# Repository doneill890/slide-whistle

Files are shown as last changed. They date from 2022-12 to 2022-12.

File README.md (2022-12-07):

# Autonomous Slide Whistle Portfolio
This repo contains a summary of the design of a slide whistle and LCD screen that could be controlled in parallel with an MCU and an FPGA. The design and results of the Project are documented here, along with the necessary source files.

The website presenting this information nicely can be accessed at [https://doneill890.github.io/slide-whistle/](https://doneill890.github.io/slide-whistle/)

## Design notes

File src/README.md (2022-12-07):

# Project file sources

This project used source files in three capacities. The MCU used embedded C files for the STM32L4 processor to drive the motor, send data to the FPGA, and drive the transistors turning the fan on and off. The FPGA used Systemverilog to describe the hardware needed to recieve information from the MCU via SPI, synchronize it, and send it with the correct configuration to the LCD screen. Finally, the 3D printed parts were all created in SolidWorks, and their files are included here. Note that these solidworks files were based in part on the CAD representations for similar gears provided by McMaster-Carr [[3](https://www.mcmaster.com/gears/metal-gears-and-gear-racks-20-pressure-angle/)]

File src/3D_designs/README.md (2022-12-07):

# 3D Design CAD files

All of the 3D printed parts of this project were designed using SolidWorks CAD software. The files for these parts can be found here, along with an assembly that indicates how to put them together. They were adapted from the 3D representations of several gears distributed by McMaster-Carr [[3](https://www.mcmaster.com/gears/metal-gears-and-gear-racks-20-pressure-angle/)]. Each part was printed at Harvey Mudd's Makerspace using FLSUN Super Racer printers using PLA provided by the school at no cost.

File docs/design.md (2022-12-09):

---
layout: page
title: Design
permalink: /design/
---

# New Hardware

There are several pieces of new hardware in this project, including the stepper motor that moves the slide whistle pull rod to different locations, the fan that blows air into the mouth piece, and the LCD that displays the song title and notes. The specific design process for implementing these features are detailed in the sections below.

# Microcontroller Design

The MCU performs three main functions: it controls the stepper motor to move the slide whistle pull rod to play different notes, it sends the song title and note information to the FPGA over SPI, and it controls the fan to blow air into the slide whistle mouthpiece. 

To control the stepper motor, the MCU sends pulses that correspond to steps (1.8° rotations of the motor) and a direction signal (to indicate clockwise or counterclockwise rotation) to an A4988 stepper motor driver. The A4988 then sends the appropriate signals to the coils in the stepper motor. The wiring for this setup can be seen on the Documentation page. In order to send an exact number of pulses to the stepper motor to move the slide whistle pull rod to a specific location, the Timer 16 peripheral was used in one-shot PWM mode along with the repetition counter register (RCR) set to the desired number of pulses. In one-shot mode, the timer is disabled after one period of the PWM has finished. If the repetition counter register is not 0, however, the timer update event is masked, so the timer continues running [[1](https://www.st.com/resource/en/application_note/dm00236305-generalpurpose-timer-cookbook-for-stm32-microcontrollers-stmicroelectronics.pdf)]. Instead, the RCR decrements after each pulse, and the timer is only disabled once the RCR reaches 0 and the desired number of pulses have been sent.

To send the name of the song to the FPGA, the SPI peripheral was used, along with a GPIO pin to indicate to the FPGA if the information sent is the name of the song or a song note (which determines where the FPGA displays the information on the LCD). 

Since the fan requires 12V and more current than the MCU can safely provide, the MCU could not drive the fan directly. Instead, the MCU controls an NPN transistor (which acts as a switch) to turn the fan on and off. The wiring for this can be seen in the Documentation section.

# FPGA Design

As mentioned above, the FPGA was set up to display characters on the LCD. It was wired using the schematic shown in the Documentaion page. The LCD in this case uses a Hitachi HD44780U LCD controller chip. The FPGA was implemented in a way that could mimic what was described in this controller’s datasheet [[2](https://circuitdigest.com/sites/default/files/HD44780U.pdf)]. This involved creating several finite state machines. 

<div style="text-align: center">
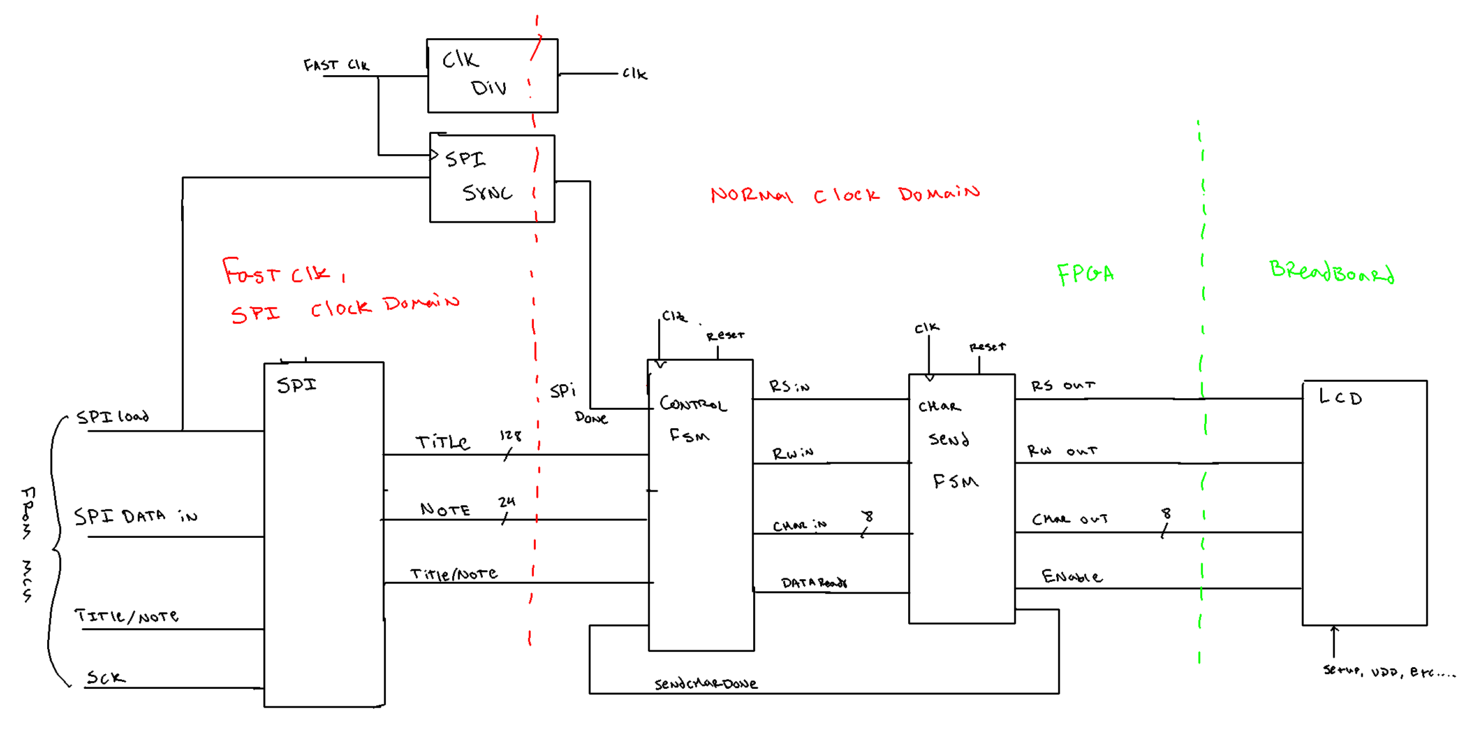
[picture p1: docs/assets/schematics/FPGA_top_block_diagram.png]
  
  <p  style="font-style: italic"> Top level diagram of each part of the FPGA design</p>
</div>

The first FSM, shown below, used to send data to the screen, works as follows: it waits for data to come in from the controller FSM, indicated by a dataReady signal rising to 1. Then it goes through the steps to send the inputs of the correct RS, R/W, Data, and Enable signals to the LCD controller. Once it is done, it raises a 'sendCharDone' signal back to the controller FSM to indicate that the transaction is complete and a new one can be made. This FSM then sits in a wait state again until the controller sends more data.

<div style="text-align: center">
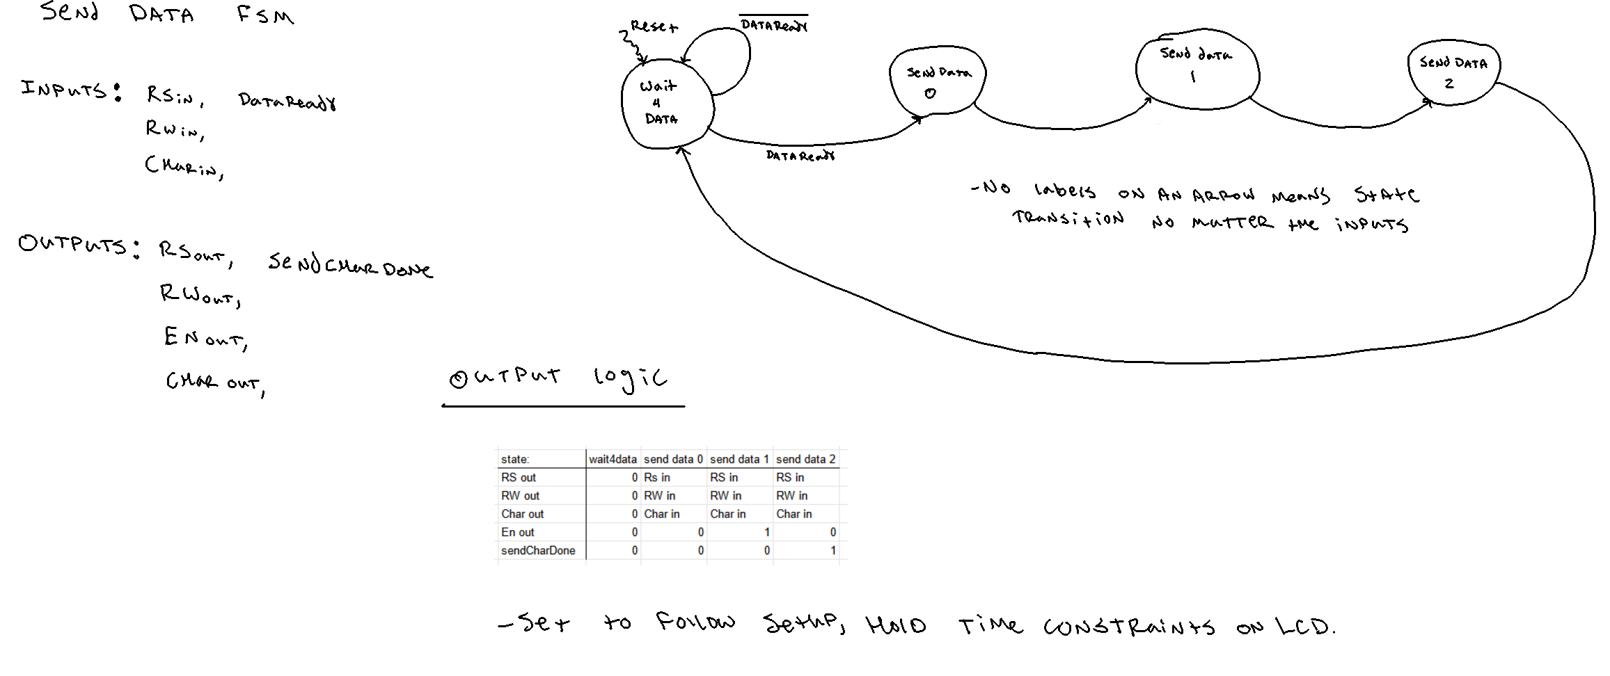
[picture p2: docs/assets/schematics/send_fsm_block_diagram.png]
  
  <p  style="font-style: italic"> FSM for sending data to LCD controller</p>
</div>

The controller FSM is rather more complicated, as it has to decide the setup signals being sent to the LCD and time all the data correctly. Its diagram is shown below. It begins in an initial state, where it waits until a counter has gone past a value corresponding to 40ms. This is due to a 40ms startup time described by the LCD controller [[2](https://circuitdigest.com/sites/default/files/HD44780U.pdf)]. 

Then, this controller FSM sends two setup signals to the LCD to set the correct configuration registers in the LCD. These set up the LCD as having 16 lines of 2 characters and to incriment the cursor each time a character is written. Then the controller FSM goes into a wait state until it receives data from the MCU over SPI. 

When the SPI transaction is done, the controller sends a control signal to the LCD that puts the cursor in the correct position for either the title or the note. Finally, the control FSM sends all the title or note characters to the LCD. Once all the characters are sent, the control FSM goes back to the wait state to await the next chunk of data from the MCU. This entire operation relies on several counter state variables that count the number of characters sent or the time passed. The updating of these values is detailed in the image below. Each time a character is sent to the LCD, the character sender FSM described above is activated by raising the dataReady signal, and the controller FSM remains in the same state until the transaction is complete and sendCharDone is raised. This is true for both control character signals and data characters being displayed on the screen. 

<div style="text-align: center">
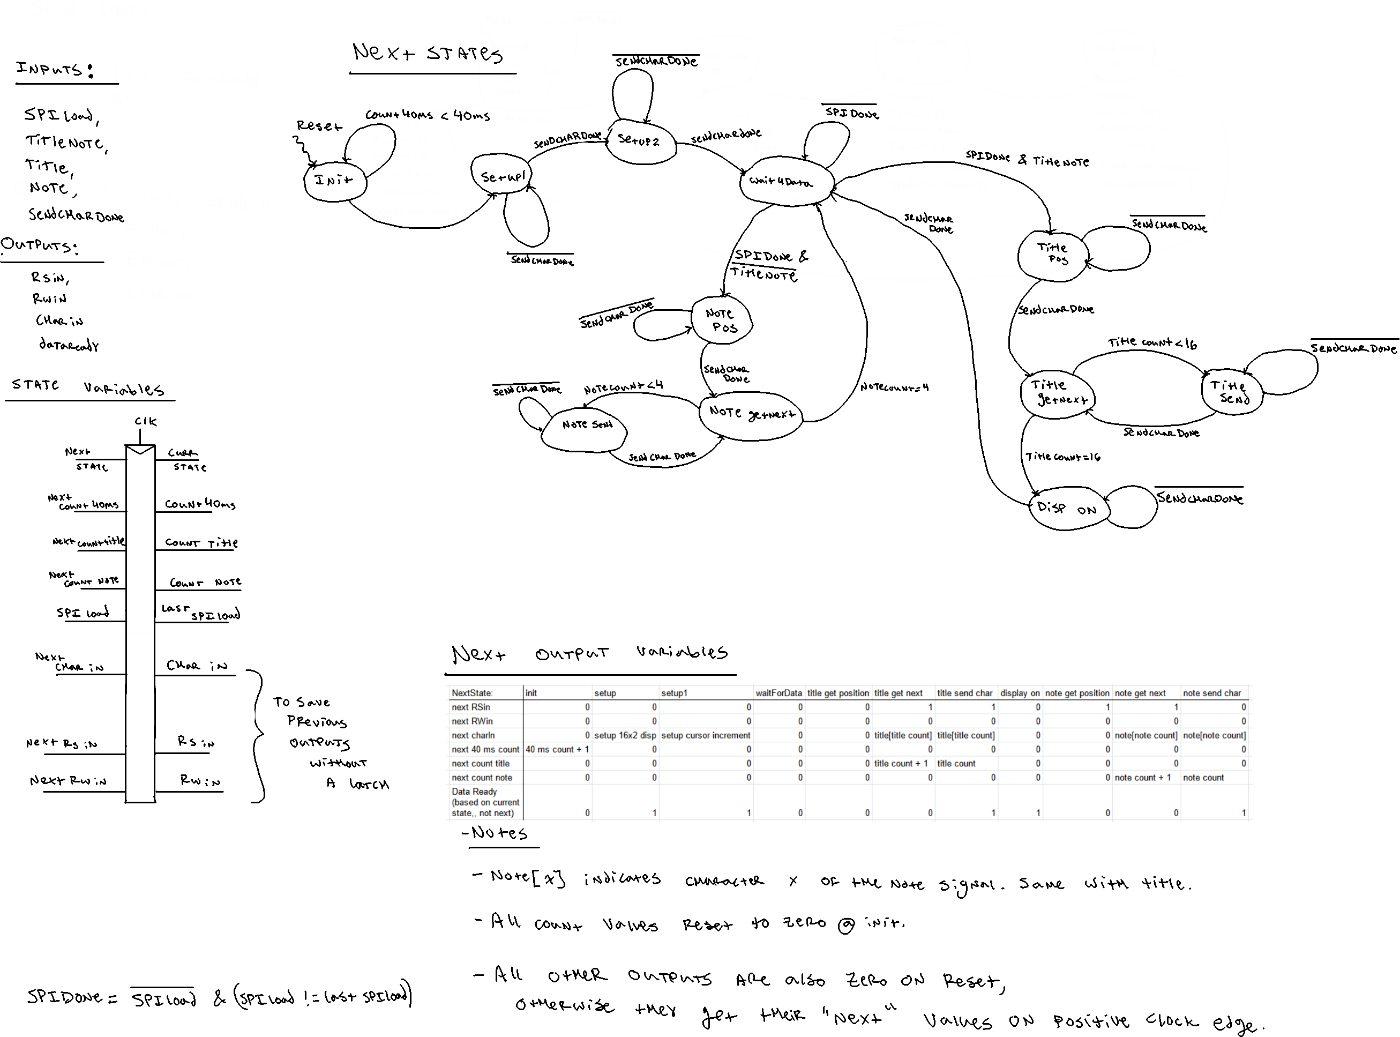
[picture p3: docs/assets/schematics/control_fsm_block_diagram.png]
  
  <p  style="font-style: italic"> FSM for controlling which data and control signals are sent to the LCD</p>
</div>

The FPGA receives the correct data to display on the screen via an SPI transaction from the MCU as the transaction controller. Data only needs to go from controller to peripheral, so the CIPO line is ignored. The SPI reception module in the FPGA listens for transactions using an spiLoad signal from the MCU. Another signal, titleNote, is used to indicate whether the transaction is sending new title data or new note data. The FPGA detects when the spiLoad signal has dropped as an indication that data transfer is done and the title or note are ready to send to the screen. 

One issue with this is that the clock for the controller and data-sending FSMs must be fairly slow. This is due to the fact that most of the commands to the screen take 37 μs [[2](https://circuitdigest.com/sites/default/files/HD44780U.pdf)]. This slow clock was divided down from a 48M MHz fast clock. The issue is that the spiLoad signal may rise and fall within less than a slow clock cycle, which means it would not be detected on the rising edge of the clock. To remedy this, a third synchronizing FSM was created and is shown below. This one used the fast 48 MHz to make sure the spiLoad signal was captured. Then, since the ratio of fast and slow clock frequencies was known, this FSM held an spiDone signal high until it could be detected by the slow clock in the controller FSM. The other data from the SPI transaction was held after the transaction completed, and the transactions come every several hundred ms, so there was no need to synchronize that data as well. In this way, all the information coming out of SPI was synchronized to the slower clock of the other FSMs. 

<div style="text-align: center">
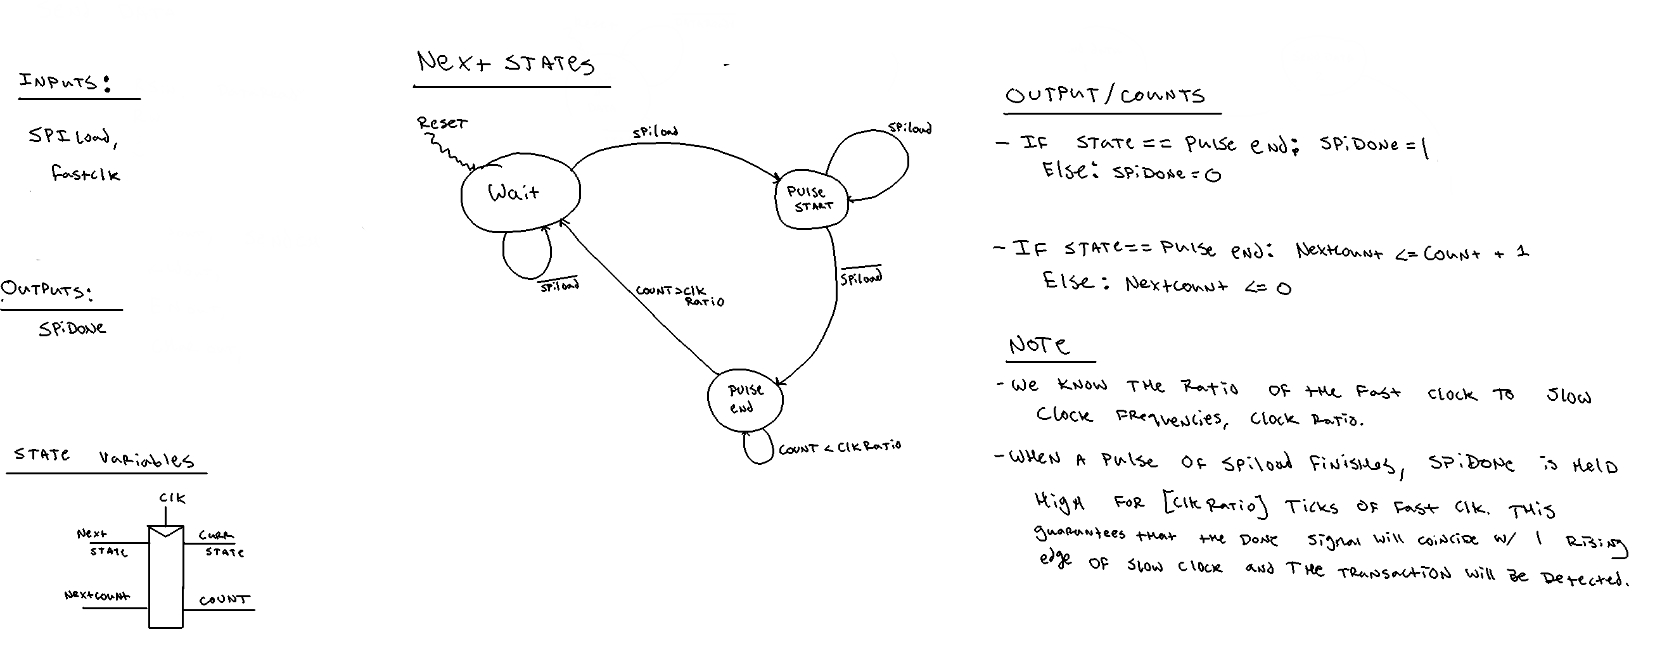
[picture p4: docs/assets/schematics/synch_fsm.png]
  
  <p  style="font-style: italic"> FSM for synchronizing data coming in from SPI to the slower clock domain</p>
</div>

# Hardware Design

The slide whistle has a 3D printed attachment from the fan to the mouthpiece of the whistle. This allows all the air coming out of the fan to be sent into the whistle, and works fairly well to play notes along the entire range of the whistle slide. This piece can be seen below.

<div style="text-align: center">
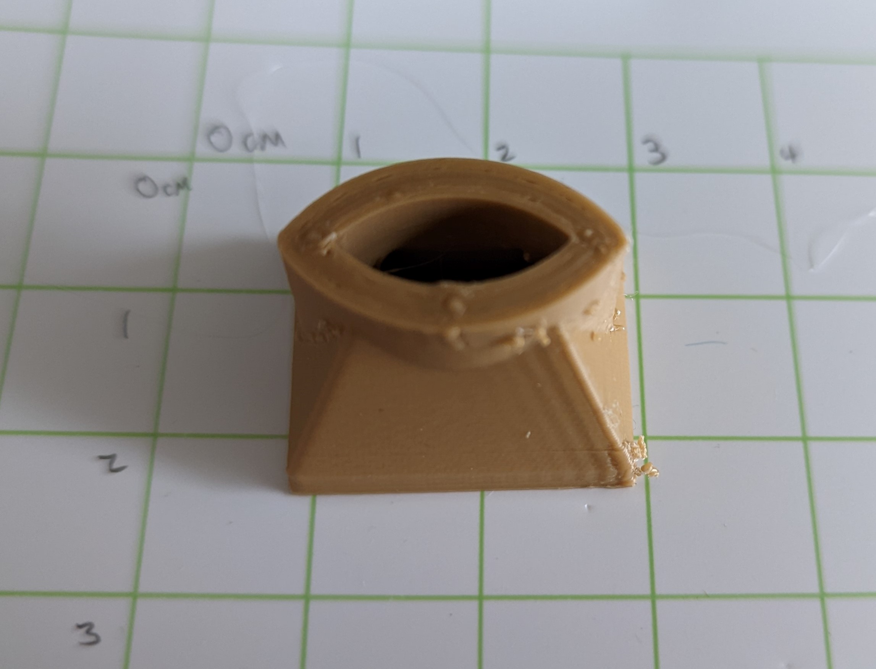
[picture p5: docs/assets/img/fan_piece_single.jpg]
  
  <p style="font-style: italic"> Adapter for slide whistle mouthpiece to attach to a 5015 fan output</p>
</div>

Another set of 3D printed pieces were used to turn the rotational motion of the stepper motor into precise translational motion of the slider. To do this, a rack, pinion, and housing for the motor were all printed out. The housing held the motor without allowing it to move and also provided axles for any additional gears that might have be needed. The pinion gear attaches to the shaft of the motor, and the rack slides back and forth in a loose track attached to the housing. These pieces are shown in the images below.

<div style="text-align: center">
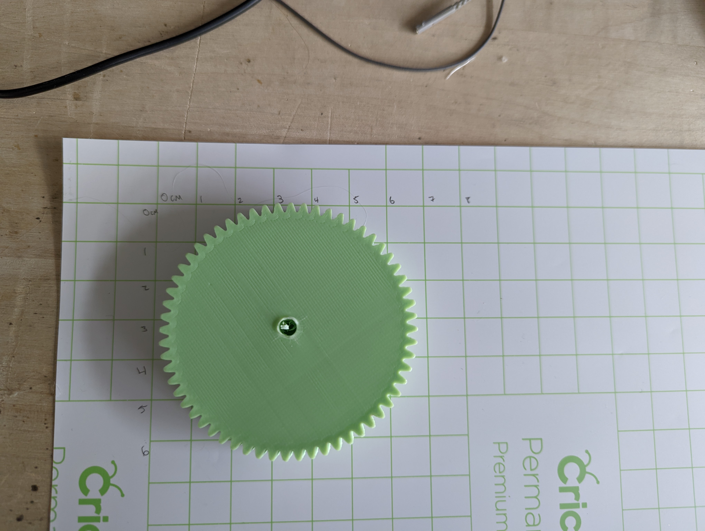
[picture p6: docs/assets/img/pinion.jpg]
  
  <p  style="font-style: italic"> 3 inch pinion gear to be attached to motor shaft</p>
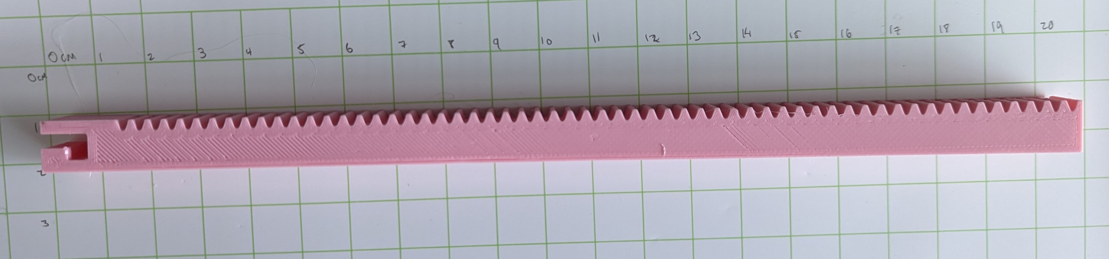
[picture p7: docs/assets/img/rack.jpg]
  
  <p  style="font-style: italic"> Rack gear to turn motor's rotational motion into translational motion along the slide of the whistle</p>
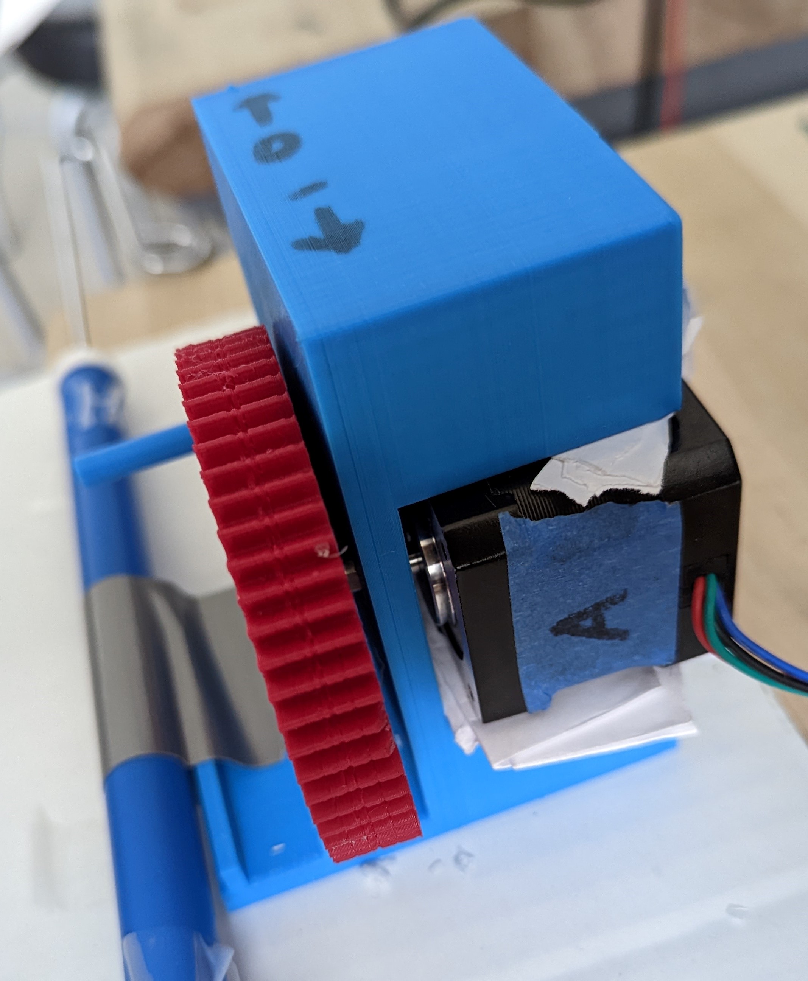
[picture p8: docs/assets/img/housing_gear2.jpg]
  
  <p  style="font-style: italic"> Motor housing with space for the motor and a track for the rack to slide when driven by the pinion gear</p>
</div>

In order to acheive a reasonably high translational speed, 3 inch pinion gears were printed. Initially, it was thought that additional speed would be needed, so more gears and axles were printed to allow the speed to be multiplied. However, increasing the speed of the gears by ratioing with a factor of x means a similar increase in torque needed and decrease in precision by a factor of x. This meant that even one ratio gear speeding up by a factor of 5 needed too much torque and did not have enough precision to hit every note along the slide correctly. Since the team was focusing on slower songs, this idea was abandoned after finding out that the translational speed acheived with a single 3 inch pinion gears was enough. The final assembled design is shown below.

<div style="text-align: center">
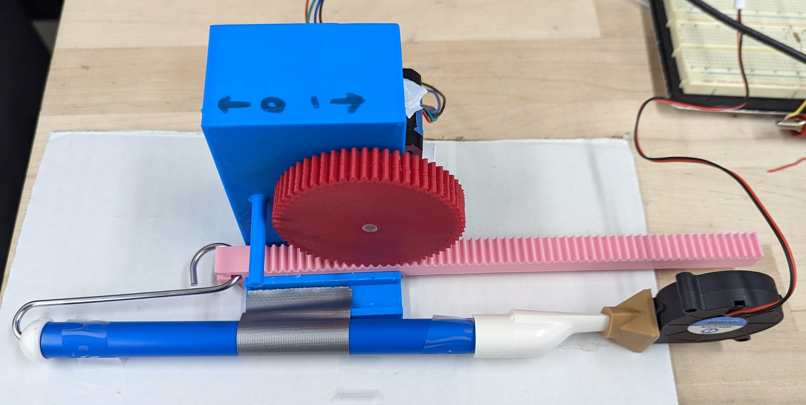
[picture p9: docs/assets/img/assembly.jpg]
    
    <p style="font-style: italic"> The entire assembly of fan, whistle adapter, motor, housing, slide whistle, rack, and pinion</p>
</div>

To encode the notes into the MCU, the team used a tuner app and a measuring tape to find the distances the slide would have to move to acheive a certain note. A function was created in the MCU that took in a note string and gave the corresponding location of the slide in units of cm away from its zero position. Since the step size, gear size, and current position were known, the MCU could then convert the new desired note location to a number of steps and a direction to travel in. It would then send this number of steps and direction to the motor controller, which would turn the gear until the whistle was set up to play the corresponding desired note. 

The steps were 1.8° each, corresponding to a 0.047 in translational motion with a 3 inch pinion gear. This allowed the high precision necessary to play notes in tune. At the highest speed, the motor could move 8 rotations per second. This means that the motor could move the rack the entire 7 inch length of the slide in about 106 ms. Both these values were determined to be satisfactory to play some simple tunes.

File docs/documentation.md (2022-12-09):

---
layout: page
title: Documentation
permalink: /doc/
---

# Schematics
<!-- Include images of the schematics for your system. They should follow best practices for schematic drawings with all parts and pins clearly labeled. You may draw your schematics either with a software tool or neatly by hand. -->

## Overall Block Diagram

<div style="text-align: left">
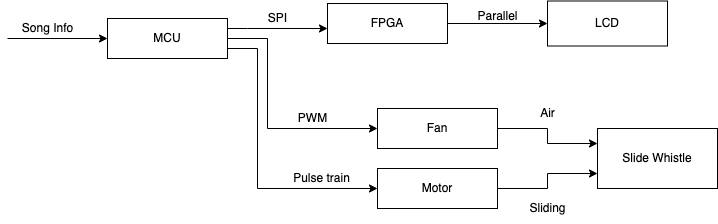
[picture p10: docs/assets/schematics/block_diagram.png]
  
</div>

## Overall system schematic

<div style="text-align: left">
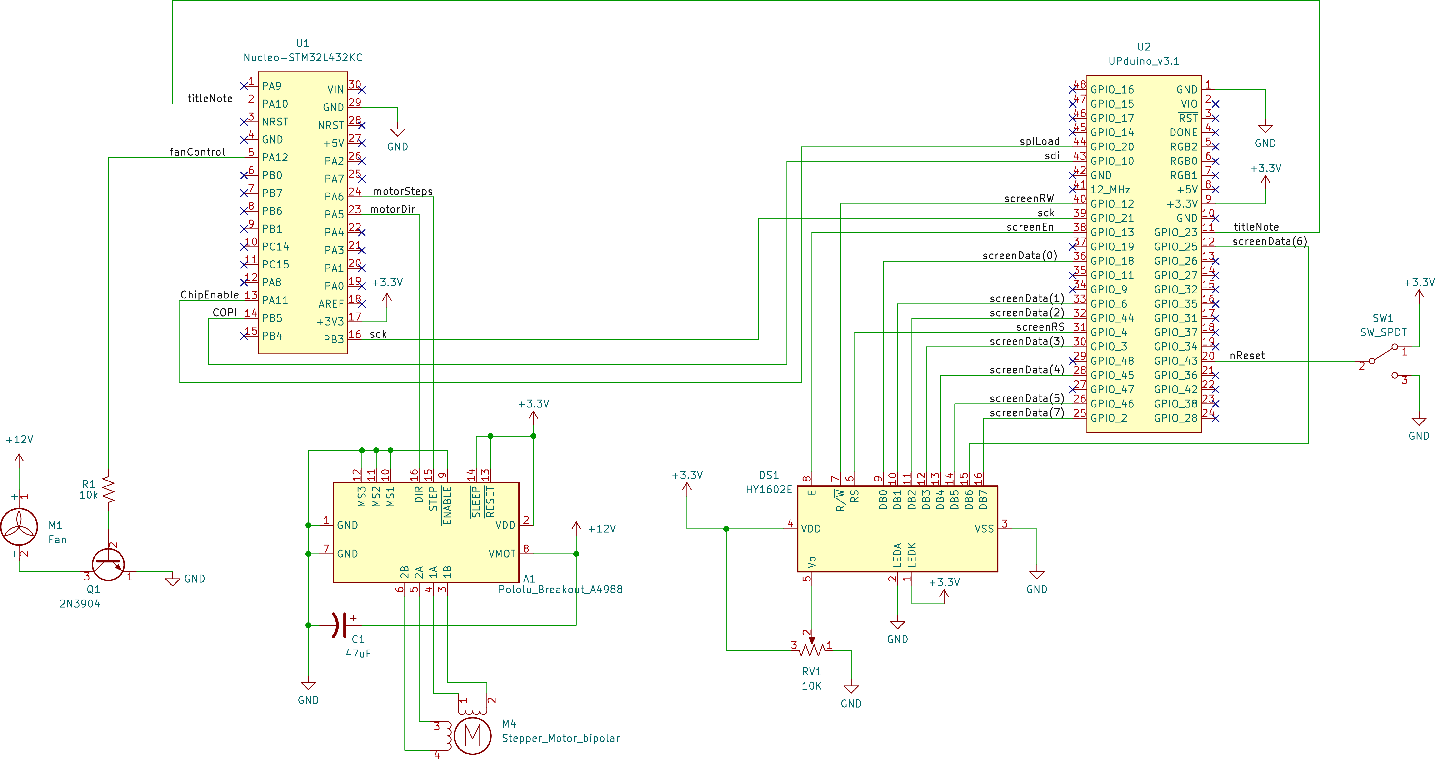
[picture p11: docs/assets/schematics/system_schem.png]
  
  <p style="font-style: italic"> Overall Schematic of entire system, including MCU, FPGA, fan, motor, and LCD. Note that both MCU and FPGA are powered via a USB connection, and the 12V sources come from benchtop power supplies. </p>
</div>

# Source Code Overview

The source code for the project is located in the Github repository [here](https://github.com/doneill890/slide-whistle/tree/main/src). 

The MCU files there can be uploaded to the STM32L432KC microcontroller on the Nucleo development board. They are used to generate the correct signals for the fan power control, motor controller IC, and SPI transactions to the FPGA. All the MCU files beginning with "STM..." were provided to the team by Prof Brake, and contain the necessary functions and definitions to use the CIMSIS library and make the design process easier. 

The FPGA files were uploaded to the ICE40UP5K FPGA on the UPduino v3.1 development board. These describe hardware that takes in SPI messages from the MCU and interfaces with the LCD to print the desired text.

The 3D design files contain the SolidWorks part files used in this project. These were manufactured using the 3D printers at Harvey Mudd's Makerspace on FLSUN Super Racer Printers using standard PLA.
# Bill of Materials

| Item | Part Number | Quantity | Unit Price | Vendor | Link |
| ---- | --- | --- | --- | --- | ---- |
| Lukmaa Slide Whistle | B091JVNBP9 | 1 | $9.99 | Amazon | [link](https://www.amazon.com/Lukmaa-Whistle-Instrument-Parent-Child-Stuffers/dp/B091JVNBP9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) |
| Focus LCDs Character Display | C162D-BW-LW65 | 1 | $13.70 | Digikey | [link](https://www.digikey.com/en/products/detail/focus-lcds/C162D-BW-LW65/13683627) |
| GDSTIME 5015 Fan | C162D-BW-LW65 | 1 | $17.99 | Amazon | [link](https://www.amazon.com/gp/product/B089Y3QPYF/ref=ox_sc_act_title_2?smid=A235LT0EDLFSAR&psc=1) |
| Pololou Stepper Controller Breakout | A4988 | 1 |  | Declan O'Neill | |
| Nucleo STM32L432KC Microcontroller | NUCLEO-L432KC | 1 |  | E155 kit | [link](https://www.st.com/en/evaluation-tools/nucleo-l432kc.html) |
| UPDuino v3.1 ICE40 UP5K FPGA |  | 1 |  | E155 kit | [link](https://upduino.readthedocs.io/en/latest/introduction/introduction.html) |
| NEMA17 Bipolar Stepper Motor | 42A02 | 1 | | Engineering stockroom| |
| PLA for 3D printing |  | 500g | | HMC Makerspace |  |
| NPN Transistor | 2N 3904 | 1 | | Engineering stockroom |  |
| 10 kOhm Potentiometer |  | 1 |  | Engineering stockroom |  |
| SPDT Push-Button Switch |  | 1 |  | E155 kit |  | 
| 47 μF Polarized Capacitor |  | 1 |  | Engineering stockroom |  |
| 1 kOhm Resistor |  | 1 |  | Engineering stockroom |  |

**Total cost: $41.68**

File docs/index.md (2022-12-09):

---
layout: page
title: Project Overview
permalink: /
exclude: true
---

# Project Abstract

In this project, the team aims to create an automated slide whistle that can play a piece of music on its own. The input to the system is an array of notes and durations and the title of the song. A microcontroller (MCU) takes this information and calculates the signals to send to a stepper motor and fan. The fan is directed to blow into the mouthpiece of the slide whistle and the motor controls a rack and pinion attached to the slide whistle pull rod, thus playing music. The MCU also sends the name of the song and the current note over a serial peripheral interface (SPI) to a field programmable gate array (FPGA) which displays that information on an LCD. All of these signals are synchronized so that the slide whistle armature moves and the fan blows to play the correct note for the correct duration and the note is displayed on the LCD all at the same time. 

# Project Motivation

A slide whistle can be a fun and pleasing instrument to play tunes with, but the tedious process of holding the slide whistle, blowing into it, and moving the rod to the correct position to play the desired notes can quickly become laborious and tiresome. The *Autonomous* Slide Whistle removes these inconveniences, providing the user with musical enjoyment at the press of a button.

# System Block Diagram

<div style="text-align: left">
  
</div>

The overall system block diagram is shown above. The microcontroller takes song information (a series of notes and durations) and plays the notes on the slide whistle by controlling a fan system and stepper motor that moves the rod on the whistle. Meanwhile, it also communicates with the FPGA over a Serial Peripheral Interface (SPI), sending the name of the song and the current note being played for the FPGA to display on the LCD.

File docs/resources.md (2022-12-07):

---
layout: page
title: Resources
permalink: /resources/
---

# References

[1] “General-purpose timer cookbook for STM32 microcontrollers” STMicroelectronics. [https://www.st.com/resource/en/application_note/dm00236305-generalpurpose-timer-cookbook-for-stm32-microcontrollers-stmicroelectronics.pdf](https://www.st.com/resource/en/application_note/dm00236305-generalpurpose-timer-cookbook-for-stm32-microcontrollers-stmicroelectronics.pdf)

[2] “HD44780U (LCD-II) Datasheet.” Hitachi Corp. [https://circuitdigest.com/sites/default/files/HD44780U.pdf](https://circuitdigest.com/sites/default/files/HD44780U.pdf)

[3] “McMaster-Carr.” [https://www.mcmaster.com/gears/metal-gears-and-gear-racks-20-pressure-angle/](https://www.mcmaster.com/gears/metal-gears-and-gear-racks-20-pressure-angle/) (accessed Dec. 07, 2022).

# Inspiration

The idea for this project came from a similar found [here](https://mitxela.com/projects/slide).

This reference project has the same main goal, to automatically play a song on a slide whistle, using an ATmega chip to drive two servos that move the slide whistle through a linkage system.

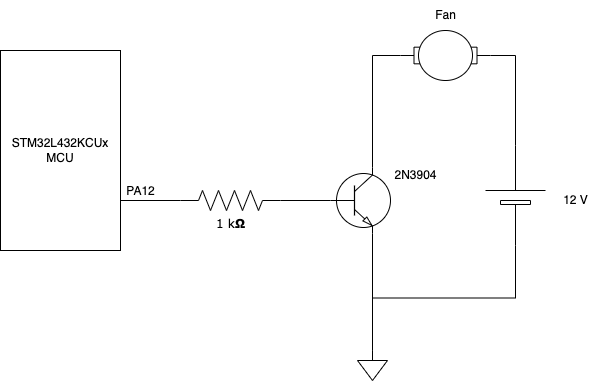
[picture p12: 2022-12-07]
docs/assets/schematics/fan_schematic.png

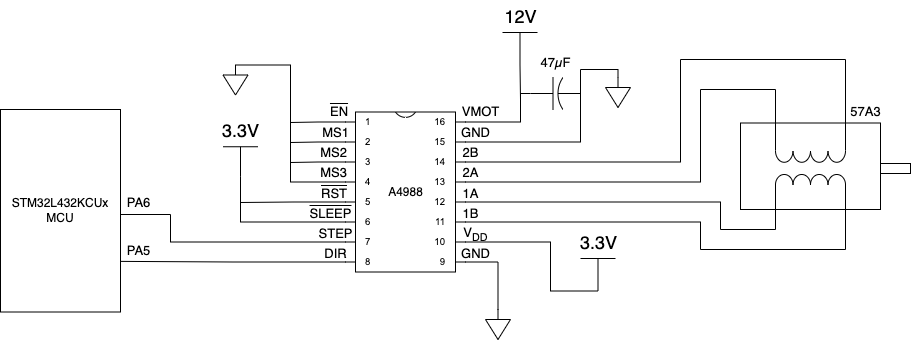
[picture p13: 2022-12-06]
docs/assets/schematics/stepper_schematic.png

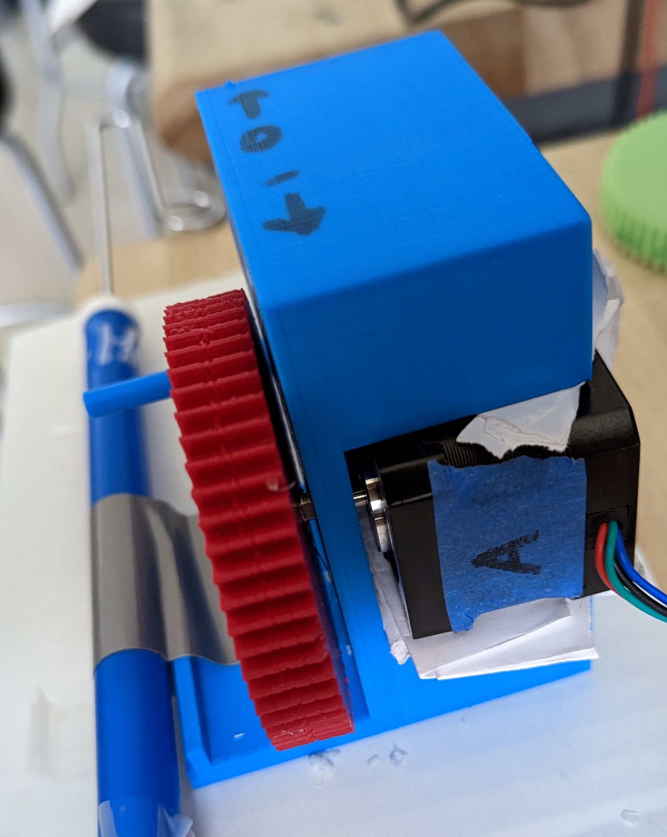
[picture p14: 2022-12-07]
docs/assets/img/housing_gear.jpg

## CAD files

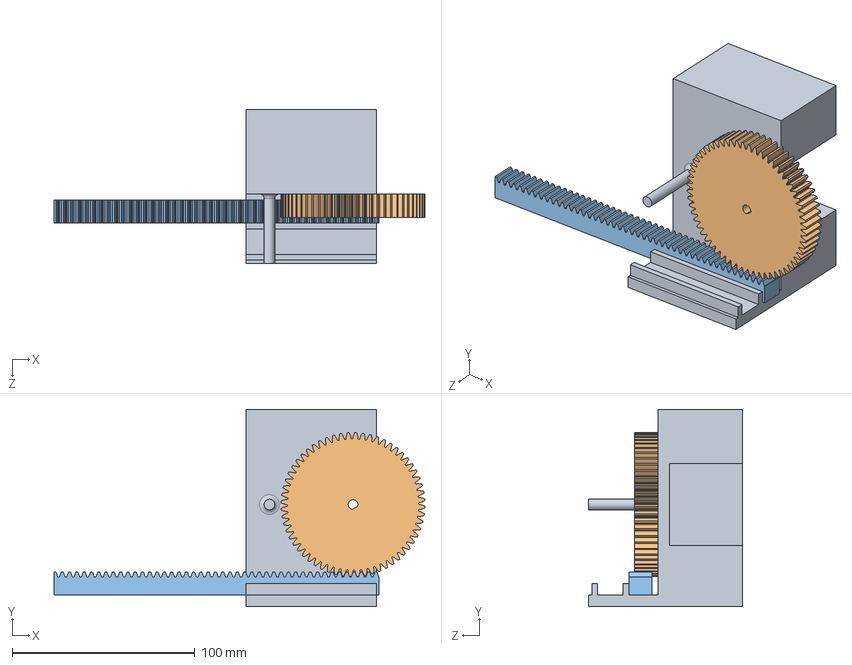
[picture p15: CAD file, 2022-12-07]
src/3D_designs/housing_gear_assembly.SLDASM
202.9 x 107.9 x 84.4 mm
stand
5172T59_Metal Gear - 20 Degree Pressure Angle
5174T21_Metal Gear Rack - 20 Degree Pressure Angle

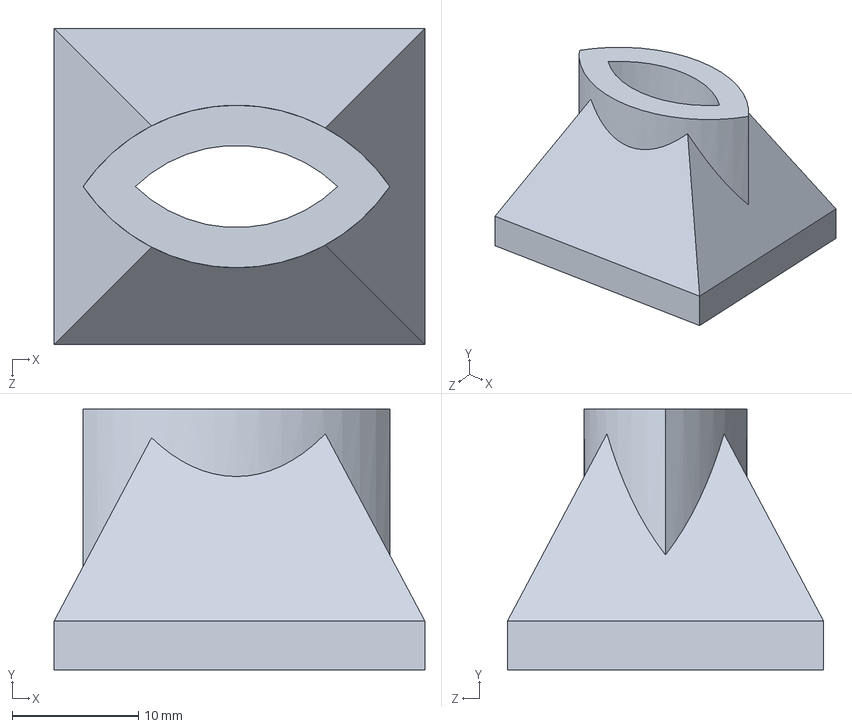
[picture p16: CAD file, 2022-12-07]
src/3D_designs/single_fan_attachment.SLDPRT
29.3 x 20.6 x 25.0 mm

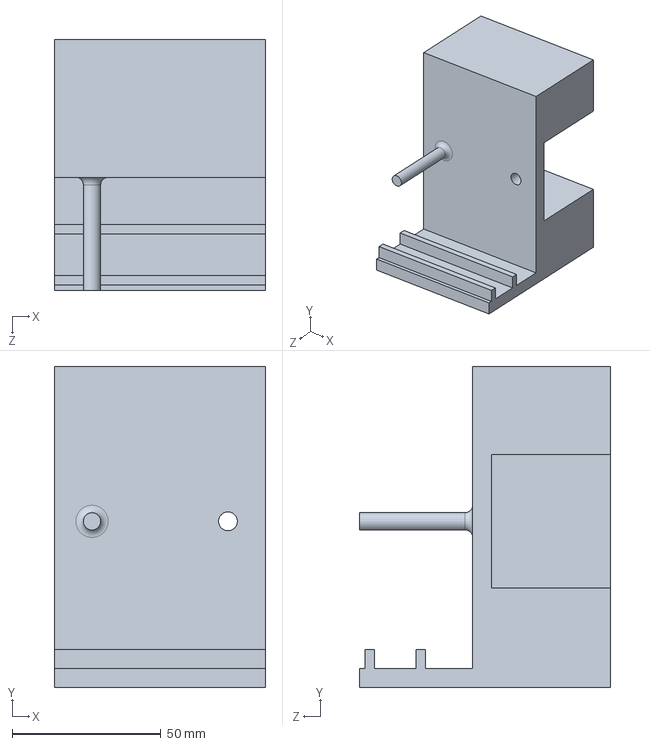
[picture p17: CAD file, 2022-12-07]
src/3D_designs/housing.SLDPRT
71.1 x 107.9 x 84.4 mm

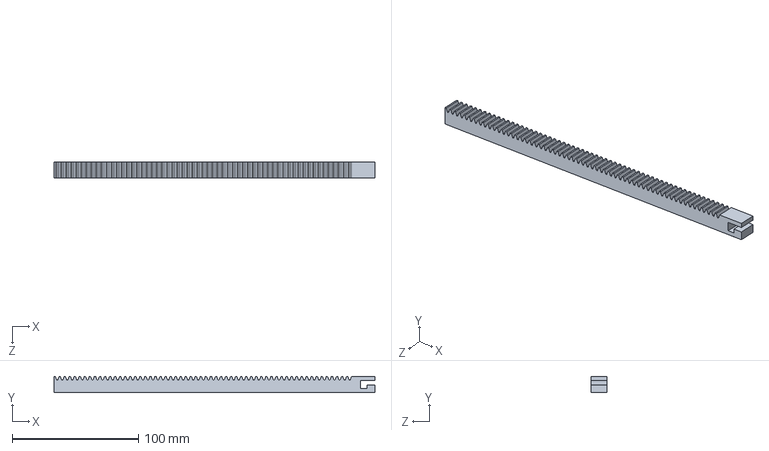
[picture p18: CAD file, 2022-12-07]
src/3D_designs/rack.SLDPRT
254.0 x 12.7 x 12.7 mm

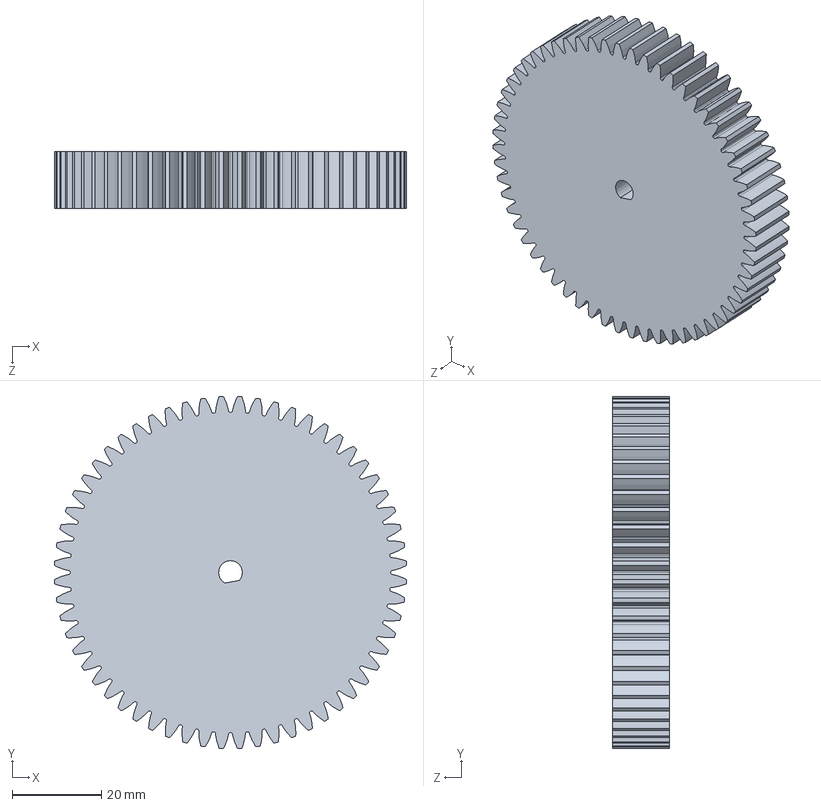
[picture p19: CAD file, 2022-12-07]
src/3D_designs/pinion.SLDPRT
78.7 x 78.7 x 12.7 mm

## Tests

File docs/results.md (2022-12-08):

---
layout: page
title: Results
permalink: /results/
---

Videos of the slide whistle and LCD playing music can be seen below 
## Circus Theme

<iframe width="880" height="495" src="https://www.youtube.com/embed/XVDk3ncent0" title="Slide Whistle Project for HMC E155 Fall 2022 | Whistle playing Circus Theme" frameborder="0" allow="accelerometer; autoplay; clipboard-write; encrypted-media; gyroscope; picture-in-picture" allowfullscreen></iframe>

<iframe width="880" height="495" src="https://www.youtube.com/embed/f81bybFK2dU" title="Slide Whistle Project for HMC E155 Fall 2022 | LCD screen playing Circus Theme" frameborder="0" allow="accelerometer; autoplay; clipboard-write; encrypted-media; gyroscope; picture-in-picture" allowfullscreen></iframe>

## Harry Potter Theme
  
<iframe width="880" height="495" src="https://www.youtube.com/embed/IlKs79siXAw" title="Slide Whistle Project for HMC E155 Fall 2022 | Whistle playing Harry Potter Theme" frameborder="0" allow="accelerometer; autoplay; clipboard-write; encrypted-media; gyroscope; picture-in-picture" allowfullscreen></iframe>

<iframe width="880" height="495" src="https://www.youtube.com/embed/RCScf1BGHj0" title="Slide Whistle Project for HMC E155 Fall 2022 | LCD screen playing Harry Potter Theme" frameborder="0" allow="accelerometer; autoplay; clipboard-write; encrypted-media; gyroscope; picture-in-picture" allowfullscreen></iframe>

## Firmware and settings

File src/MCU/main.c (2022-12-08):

/*********************************************************************
*                    SEGGER Microcontroller GmbH                     *
*                        The Embedded Experts                        *
**********************************************************************

-------------------------- END-OF-HEADER -----------------------------

File    : main.c
Purpose : defining the functions needed to play music on a slide whistle and display the
          song information on an LCD by sending it via SPI to the FPGA.

*/

#include <stdio.h>
#include "tim1.h"
#include <stm32l432xx.h>
#include "STM32L432KC.h"
#include "STM32L432KC_TIM.h"
#include <string.h>

#define IN2CM 2.54
#define MAXLEN 100 // I need a max length of the song to put into the struct, so this is arbitrary
#define STEP2CM ((3*IN2CM*1.8*3.141592653)/360) // conversion factors.
#define CM2STEP (1/STEP2CM)
#define FREQ 200 // frequency for sending pulses to the motor. higher means less time between steps.
#define Q 250 // note length definitions in ms. (Quarter)
#define E Q/2 // (Eighth)
#define H Q*2 // (Half)

struct song {
  // Struct to define everything needed to play a song.
  // this way we can define several different songs and insert it as the declared song to play
  // in the main function
  const char title[16];
  const int length; // in number of notes
  const char notes[MAXLEN][4];
  const int durations[MAXLEN];
};

const struct song harry_potter = {
    "Harry Potter",
    14,
    {"B4", "E5", "G5", "F#5", "E5", "B5", "A5", "F#5", "E5", "G5", "F#5", "Eb5", "F5", "B4"},
    {Q, Q+E, E, Q, H, Q, H+Q, H+Q, Q+E, E, Q, H, Q, Q+H}
 };

 const struct song sad_times = {
    "Wa wa wa waaaa",
    4,
    {"A5", "G#5", "G5", "F#5"}, 
    {H, H+E, H+Q, H+H}
 };

const struct song circus = {
    "Circus theme",
    27,
    {"B5", "Bb5", "B5", "Bb5", "A5", "G#5", "G5", "F#5", "G5", "A5", "G#5", "G5", "G#5", "G5", "F#5", "F5", "E5", "D5", "E5", "G5", "F5", "E5", "F5", "G5", "F5", "E5", "F5"}, 
    {Q, E, E, E, E, Q, Q, Q, Q, Q, Q, E, E, E, E, Q, Q, Q, Q, Q, Q, Q, Q, Q, Q, Q, Q}
 };

const struct song ABCs = {
    "Alphabet song",
    14,
    {"D5", "D5", "A5", "A5", "B5", "B5", "A5", "G5", "G5", "F#5", "F#5", "E5", "E5", "D5"},
    {Q, Q, Q, Q, Q, Q, H, Q, Q, Q, Q, Q, Q, H}
};

double getLoc(const char note[4]) {
    // given a note, returns a location in cm. 0 is the slide as close to the mouthpiece as possible
    
    if      (!strcmp("Bb6", note))  {return 0.0;}
    else if (!strcmp("A6", note))   {return 0.65;}
    else if (!strcmp("B5", note))   {return 2.5;}
    else if (!strcmp("Bb5", note))  {return 4.0;}
    else if (!strcmp("A5", note))   {return 4.7;}
    else if (!strcmp("G#5", note))  {return 5.5;}
    else if (!strcmp("G5", note))   {return 6.2;}
    else if (!strcmp("F#5", note))  {return 6.9;}
    else if (!strcmp("F5", note))   {return 7.7;}
    else if (!strcmp("E5", note))   {return 8.5;}
    else if (!strcmp("Eb5", note))  {return 9.3;}
    else if (!strcmp("D5", note))   {return 9.2;}
    else if (!strcmp("Db5", note))  {return 11.15;}
    else if (!strcmp("C5", note))   {return 12.2;}
    else if (!strcmp("B4", note))   {return 13.1;}
    else if (!strcmp("Bb4", note))  {return 14.3;}
    else if (!strcmp("A4", note))   {return 15.55;}
    else {return 0;}
}

void fillString(const char string[], char newStr[], int len) {
  // function to fills a string with spaces until it is len long.
  // relies on the fact that the string has been initialized with some length >= len
  // and the actual contents of the string are <= len so the rest can be filled with spaces.

  int currLen = strlen(string);

  for (int i=0; i<len; i++) {
    if (i > currLen - 1) {newStr[i] = ' ';}
    else {newStr[i] = string[i];}
  } 
}

void wait(void){
  // function to wait for the TIM16 to be done sending pulses to the motor.

  int status = checkStatus();
  while (status == 0){status = checkStatus();}
}


void sendTitle(const char title[]) {
  // Function to send the title to the FPGA via SPI, where it will put on the display

  char screenTitle[16];
  fillString(title, screenTitle, 16); // The FPGA expects 16 characters, so fill the rest 
  // of the title with spaces instead of null characters.

  digitalWrite(PA10, 1); // indicate that a title is being sent
  digitalWrite(PA11, 1); // raise spiLoad

  for (int i=0; i <16; i++){
    spiSendReceive(screenTitle[i]);
  }

  digitalWrite(PA11, 0); // drop spiLoad
}

void sendNote(const char note[]) {
  // Function to send the note to the FPGA via SPI, where it will put on the display

  char screenNote[3];
  fillString(note, screenNote, 3);  // The FPGA expects 16 characters, so fill the rest 
  // of the title with spaces instead of null characters.

  digitalWrite(PA10, 0); // indicate that a note is being sent
  digitalWrite(PA11, 1); // raise spiLoad

  for (int i=0; i <3; i++){
    spiSendReceive(screenNote[i]);
  }

  digitalWrite(PA11, 0); // drop spiLoad
}

float goToPos(float currPosition, float nextPosition) { 
  // function to go to the next position (given in cm) using the motor
  // and update the current one.

  float dist = currPosition - nextPosition; // in cm
  int steps = dist*CM2STEP;
  float realNextPos = currPosition - steps*STEP2CM; // calculate the next position since we won't hit next position exactly.
  if (steps < 0) {steps = -steps;}
  
  if (dist < 0){ setDirection(0); } 
  else { setDirection(1); }
  
  if (steps == 0) {} // do nothing if we're already in the right place
  else {
    setFrequency(FREQ, steps, 1); // sends steps to motor
    wait(); // waits for step sending timer to be done counting up steps
  }
  return realNextPos;
}


void setup(void) {
  // setup function to ensure all the clocks and configuration registers are turned on.

  // Enable GPIOA, B, C, TIM16 clock
  RCC->AHB2ENR |= (RCC_AHB2ENR_GPIOAEN | RCC_AHB2ENR_GPIOBEN | RCC_AHB2ENR_GPIOCEN);
  RCC->APB1ENR1 |= (RCC_APB1ENR1_TIM6EN);

  
  initSPI(1, 0, 0);
  configureGPIO();
  
  // initialize TIM6 for delay, TIM16 for sending pulses to the stepper controller
  initTIM(TIM6);
  configureTIM16();

  pinMode(PA11, GPIO_OUTPUT);  // LOAD
  pinMode(PA10, GPIO_OUTPUT);   // titleNote
  pinMode(PA2, GPIO_INPUT);    // starter pin
  pinMode(PA12, GPIO_OUTPUT);  // fan cntrl pin

  delay_millis(TIM6, 200);// wait for LCD to startup before sending data.

}


/*********************************************************************
*
*       main() 
*
*  Function description
*   initialize data to play, send the title to the screen,
*   then play the song by putting the correct notes on the screen
*   and moving the motor to the right place
*/
int main(void) {
  struct song songToPlay = circus; // LOAD IN SONG DATA HERE

  float currPosition = 0; // in steps away from zero in cm
  float nextPosition;

  setup();
  sendTitle(songToPlay.title);
   
  while(1) {

    while(digitalRead(PA2)){} // wait until button press to start song
      
    digitalWrite(PA12, 1); // turn fan on
    delay_millis(TIM6, 3000); // wait 3 seconds for the fan to start up

    for (int i = 0; i < songToPlay.length; ++i){
      
      sendNote(songToPlay.notes[i]); // send the next note
      nextPosition = getLoc(songToPlay.notes[i]); // get the next location
      currPosition = goToPos(currPosition, nextPosition); // go to that location
      delay_millis(TIM6, songToPlay.durations[i]); // wait for duration of note

    }
    sendNote("end"); // at the end of the song, turn off the fan and reset the motor.
    digitalWrite(PA12, 0);
    currPosition = goToPos(currPosition, 0);
  }
}


/*************************** End of file ****************************/

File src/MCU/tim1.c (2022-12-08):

#include "tim1.h"

void configureTIM16(){
  // function for enabling all the necessary registers to have TIM16 work in
  // pulse mode and send an arbitrary number of pulses. 

  *RCC_APB2EN |= (1 << 17);     // enable PCLK2

  *TIM16_CCMR1 |= (1 << 6);     // set OC1M[2:0] = 110 to enter PWM mode 1
  *TIM16_CCMR1 |= (1 << 5);

  *TIM16_CCMR1 |= (1 << 3);     // enable OC1PE for read/write operations on the preload register
  *TIM16_CR1 |= (1 << 7);       // ARPE auto-relaod preload enable
  *TIM16_CCER |= (1 << 0);      // capture/compare 1 output enable
  *TIM16_CCER |= (1 << 2);      // OC1N is output now, idk what this does

  *TIM16_BDTR |= (1 << 15);     // main output enable
  *TIM16_CCER |= (1 << 0);      // capture/compare 1 output enable
  *TIM16_CCER |= (1 << 2);      // capture/compare 1 complementary output enable
  
  TIM16->DIER |= _VAL2FLD(TIM_DIER_UIE, 1); // update interrupt enable
  TIM16->SR &= ~_VAL2FLD(TIM_SR_UIF, 1); // clear update interrupt flag
}

void configureGPIO(){
  // function for configuring GPIO block A to send pulses from TIM16.

  *RCC_AHB2ENR |= (1 << 0);         // enable GPIO A clock

  *GPIOA_MODER &= ~(1 << 2*6);      // set pin A6 to alternate function mode
  *GPIOA_MODER |= (1 << (2*6+1));
  
  int pin = 5;
  GPIOA->MODER |= (0b1 << 2*pin);  // set pin A5 as output
  GPIOA->MODER &= ~(0b1 << (2*pin+1));

  GPIOA->AFR[0] |= _VAL2FLD(GPIO_AFRL_AFSEL6, 0b1110); // set alternate function for PWM
}

void setDirection(int val) {
    // function to set the pin indicating motor direction correctly
    // 1 is moving the slide closer to the mouthpiece for higher notes
    // 0 is moving the slide away from the mouthpiece for lower notes

    int pin = 5;
    if (val) {
      GPIOA->ODR |= (1 << pin);
    }
    else{
      GPIOA->ODR &= ~(1 << pin);
    }
}

void setFrequency(int f, int steps, int on){
  // function to set the frequency of the pulses sent to the motor and then send 
  // [steps] number of pulses.

  TIM16->SR &= ~_VAL2FLD(TIM_SR_UIF, 1);   // clear update interrupt
  *TIM16_PSC = 1; // in-comping clock is 4 GHz, clock frequency after prescalar is 2 GHz

  *TIM16_ARR = (int) 2*1000000/f;
  if (on){
    *TIM16_CCR1 = (int) 2*1000000/(2*f);
  } 
  else{
    *TIM16_CCR1 = 0;
  }

  TIM16->RCR &= _VAL2FLD(TIM_RCR_REP, 0); // clear RCR rep value
  TIM16->RCR |= _VAL2FLD(TIM_RCR_REP, steps-1);  // set RCR to number of counts
  TIM16->EGR |= _VAL2FLD(TIM_EGR_UG, 1);   // update generate
  TIM16->CR1 |= _VAL2FLD(TIM_CR1_OPM, 1);  // enable one pulse mode

  TIM16->SR &= ~_VAL2FLD(TIM_SR_UIF, 1);   // clear update interrupt
  TIM16->CR1 |= _VAL2FLD(TIM_CR1_CEN, 1);  // enable counter
}


int checkStatus(){
  // function to check if the ulses have completed sending (an update interrupt event raises.

  return _FLD2VAL(TIM_SR_UIF, TIM16->SR);  // check for update interrupt
  
}

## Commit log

2022-12-03 update bill of materials
2022-12-06 uploaded stepper schematic
2022-12-06 updated schematics
2022-12-07 added fan schematic
2022-12-07 added solidworks files to src
    [housing.SLDPRT, housing_gear_assembly.SLDASM, pinion.SLDPRT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]
2022-12-07 added overall schematic and updated to reflect
2022-12-08 added all materials to BOM.
2022-12-08 small BOM update
2022-12-08 edits to BOM and video names
2022-12-08 updated videos and BOM
2022-12-08 added motor to BOM
2022-12-08 fixed BOM columns
2022-12-09 updated schematic to show motor
